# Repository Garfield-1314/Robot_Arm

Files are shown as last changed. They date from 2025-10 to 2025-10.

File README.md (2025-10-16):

# Robot_Arm

## 项目简介
本项目为一个多自由度的机械臂系统，包含机械结构设计、固件开发（基于Arduino）、OpenMV视觉识别、以及多种应用示例（如物块抓取、垃圾分类、三子棋等）。适用于机器人学习、人工智能实验、机械臂控制等场景。

## Project Description
This project is a multi-degree-of-freedom desktop robotic arm system, including mechanical design, firmware development (Arduino-based), OpenMV vision recognition, and various application examples (such as object grasping, garbage classification, tic-tac-toe, etc.). It is suitable for robotics learning, AI experiments, and robotic arm control scenarios.

---

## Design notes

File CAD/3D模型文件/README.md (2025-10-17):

# 机器人手臂 CAD 3D模型文件

## 文件说明

- `ROBOT ARM v30.3mf`：3MF 3D打印机分盘文件，可使用拓竹3D打印机打印：1，2盘为天蓝色；3盘为粉色；4盘为白色；5盘为黄色；6盘蓝色；7盘黑色
- `ROBOT ARM v30.step`：STEP格式的机械臂三维模型文件。

## 使用方法

1. 使用支持3MF或STEP格式的CAD软件（如SolidWorks、Fusion 360、AutoCAD等）打开对应文件。
2. 可用于3D打印、机械设计、仿真等场景。

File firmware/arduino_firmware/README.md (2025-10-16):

# Arduino Robot Arm Firmware / Arduino 机械臂固件

## 简介 | Introduction
本项目为基于 Arduino 平台的机械臂控制固件，适用于 ESP32（如 Wemos D1 R32）等主控板。固件实现了机械臂的基本运动控制、插补算法、末端执行器（如舵机夹爪）控制、限位检测、命令解析等功能。

This project is a robot arm control firmware based on the Arduino platform, suitable for ESP32 (such as Wemos D1 R32) and other mainboards. The firmware implements basic motion control, interpolation algorithms, end-effector (such as servo gripper) control, endstop detection, command parsing, and more.

## 主要功能 | Main Features
- 多轴步进电机控制，支持 Ramps 驱动板
- 运动插补算法，实现平滑轨迹规划
- 舵机夹爪控制
- 端点限位检测，保证运动安全
- 命令解析与队列管理，支持外部串口/网络指令
- 日志记录与调试输出

- Multi-axis stepper motor control, supports Ramps driver board
- Motion interpolation algorithm for smooth trajectory planning
- Servo gripper control
- Endstop detection for safe operation
- Command parsing and queue management, supports external serial/network commands
- Logging and debug output

## 主要文件说明 | Main Files
- `arduino_firmware.ino`：主程序入口 | Main program entry
- `RampsStepper.*`：步进电机控制与驱动 | Stepper motor control and driver
- `interpolation.*`：插补算法实现 | Interpolation algorithm
- `servo_gripper.*`：舵机夹爪控制 | Servo gripper control
- `endstop.*`：限位开关检测 | Endstop detection
- `command.*`：命令解析与执行 | Command parsing and execution
- `equipment.*`：机械臂设备抽象 | Robot arm equipment abstraction
- `logger.*`：日志与调试输出 | Logging and debug output
- `config*.h`：硬件配置（如引脚定义、参数设置）| Hardware configuration (pin definitions, parameters)
- `pinout/`：不同主控板的引脚映射 | Pin mapping for different mainboards

## 使用说明 | Usage
1. 根据实际硬件修改 `config.h` 和 `pinout/` 下的引脚定义。
2. 使用 Arduino IDE 或 PlatformIO 编译并上传固件到主控板。
3. 通过串口或网络发送控制指令，实现机械臂运动。

1. Modify `config.h` and pin definitions in `pinout/` according to your hardware.
2. Compile and upload the firmware to the mainboard using Arduino IDE or PlatformIO.
3. Send control commands via serial or network to operate the robot arm.

## 适用硬件 | Supported Hardware
- 主控板：ESP32 等
- 舵机、限位开关等外设

- Mainboard: ESP32 (e.g. Wemos D1 R32), Arduino Mega, etc.
- Servo, endstop switches, and other peripherals

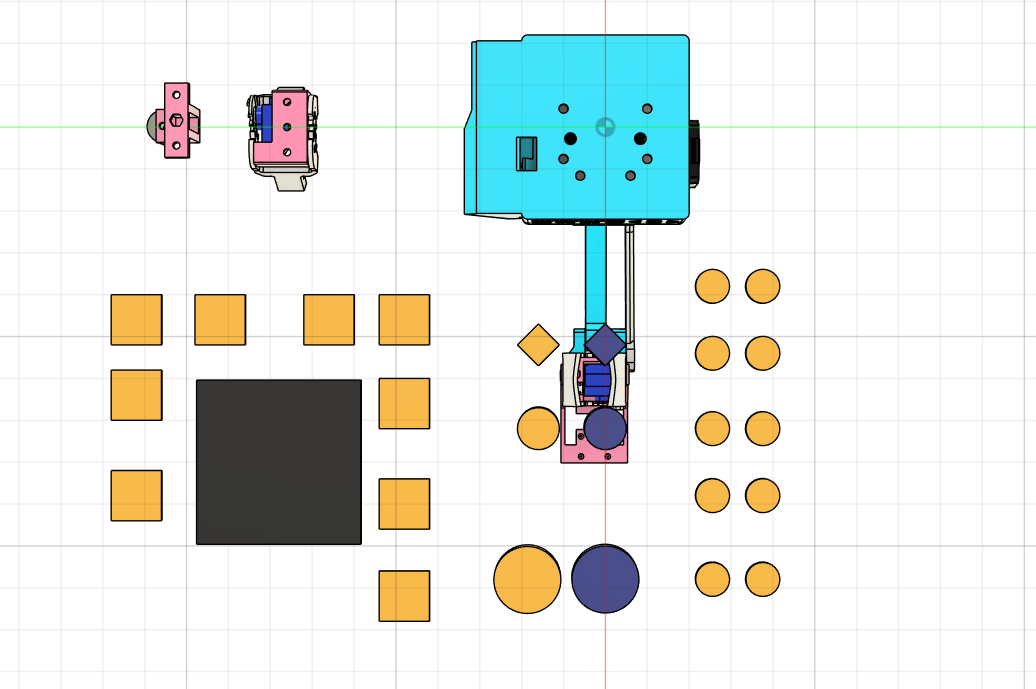
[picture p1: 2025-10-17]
CAD/3D模型文件/底视图.png

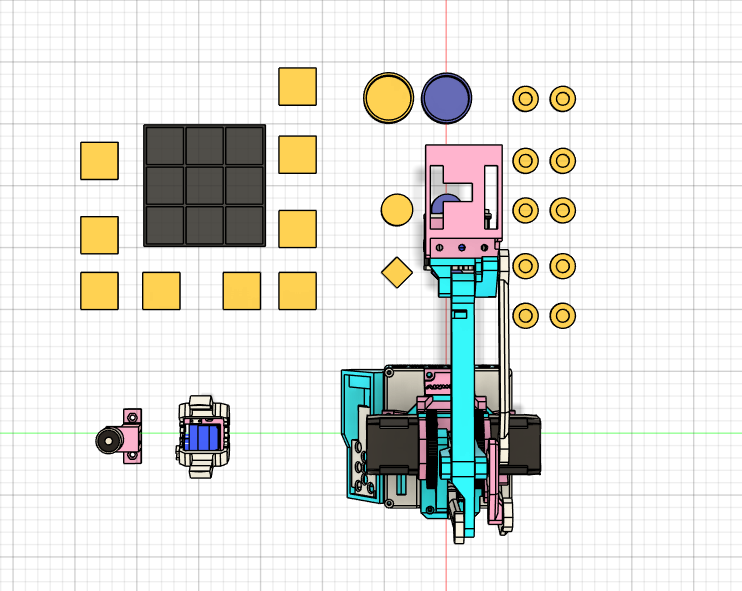
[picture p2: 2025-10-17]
CAD/3D模型文件/顶视图.png

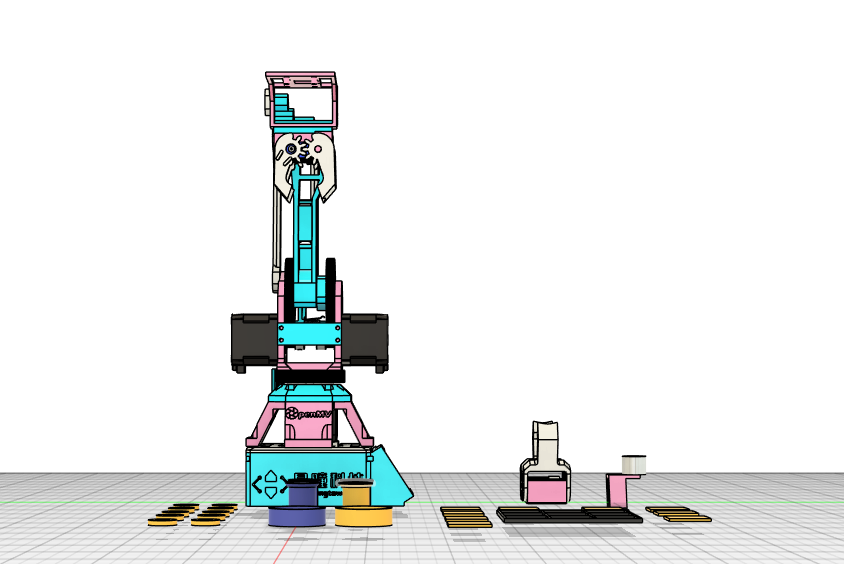
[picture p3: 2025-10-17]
CAD/3D模型文件/右视图.png

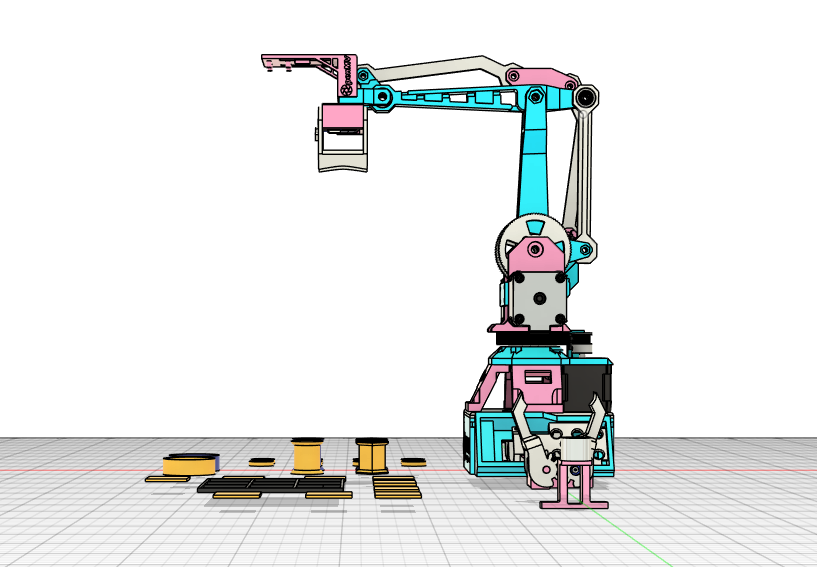
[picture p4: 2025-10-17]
CAD/3D模型文件/后视图.png

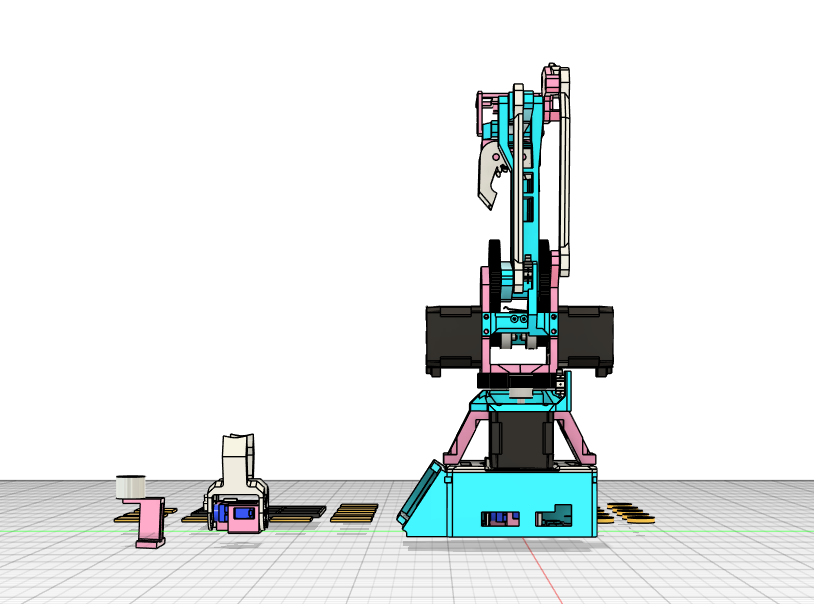
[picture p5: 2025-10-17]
CAD/3D模型文件/左视图.png

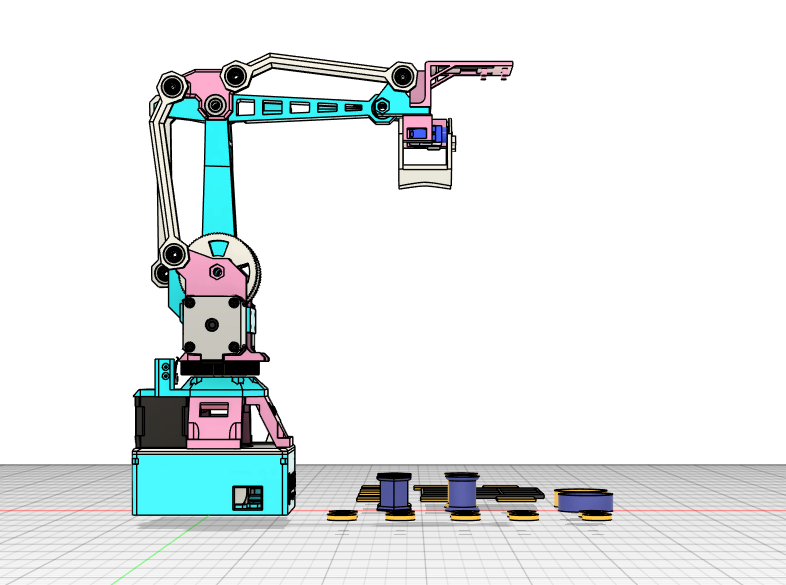
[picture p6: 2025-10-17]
CAD/3D模型文件/前视图.png

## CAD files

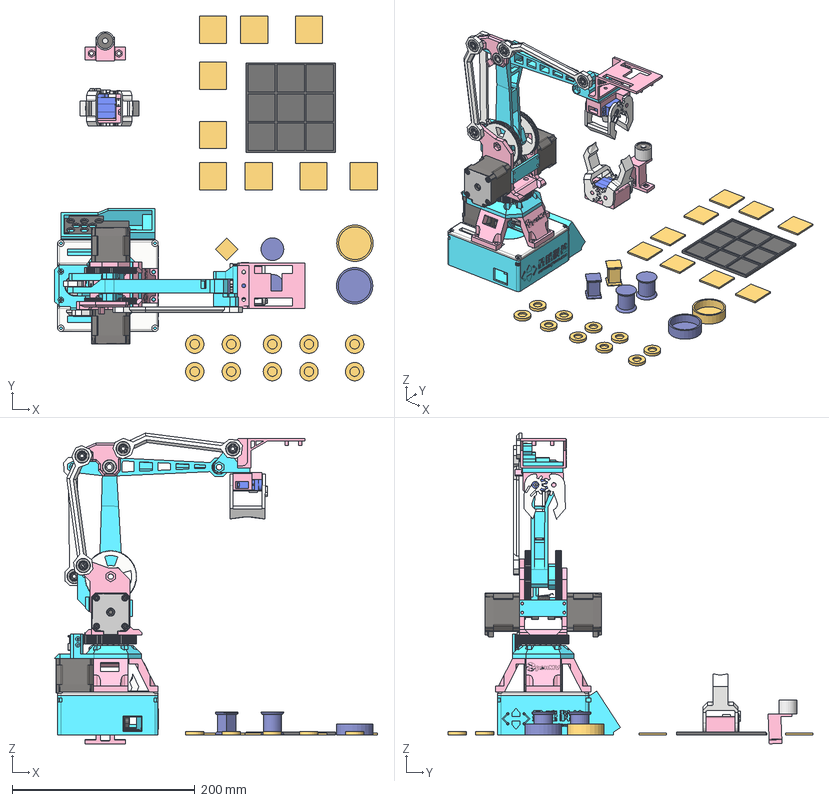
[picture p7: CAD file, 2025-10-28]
CAD/3D模型文件/ROBOT ARM v40.step
353.5 x 399.0 x 340.1 mm
零部件2
零部件2_1
零部件3
零部件4
零部件3_1
零部件4_1
零部件5
零部件3_3 x 3
零部件3_2 x 3
零部件3_4 x 3
零部件2_2
零部件2_3
零部件2_4
零部件3_5 x 7
零部件2_5 x 2
零部件2_6
零部件2_7
零部件2_8
零部件2_9
零部件3_6 x 6
零部件2_10
零部件2_11
零部件2_12
零部件2_13
零部件1
零部件2_14
零部件3_7
零部件4_2
零部件1_1
底座_1
PCB盖
零部件1_2
零部件2_15
零部件2_16
零部件3_8
零部件4_3
零部件2_17
零部件2_18
零部件2_19
零部件2_20
零部件2_21
零部件3_9
零部件4_4
零部件2_22
hand_8
零部件2_23
零部件1_3
零部件1_4
零部件1_5 x 3
零部件2_24
零部件3_10
三子棋棋子 x 10
零部件4_5
零部件5_1
棋盘

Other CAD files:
CAD/3D模型文件/ROBOT ARM v40.3mf
CAD/3D模型文件/ROBOT ARM v40.stl

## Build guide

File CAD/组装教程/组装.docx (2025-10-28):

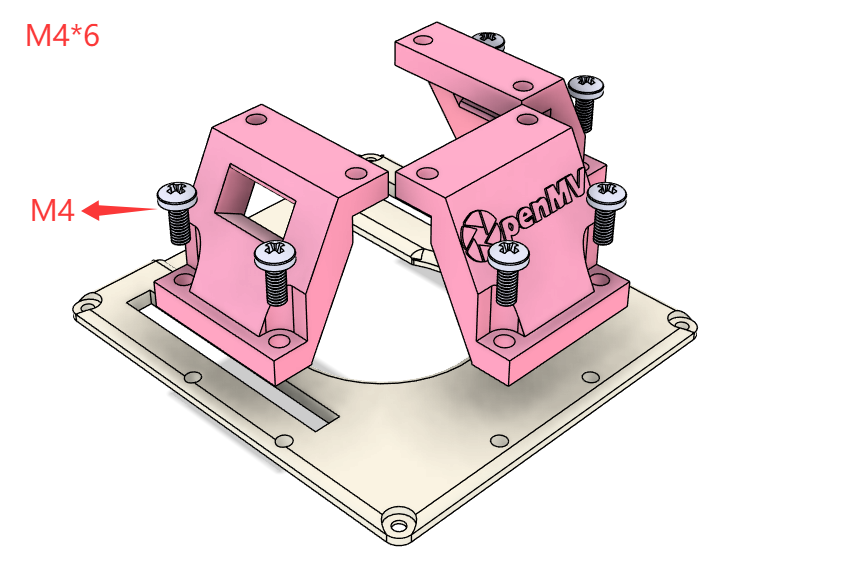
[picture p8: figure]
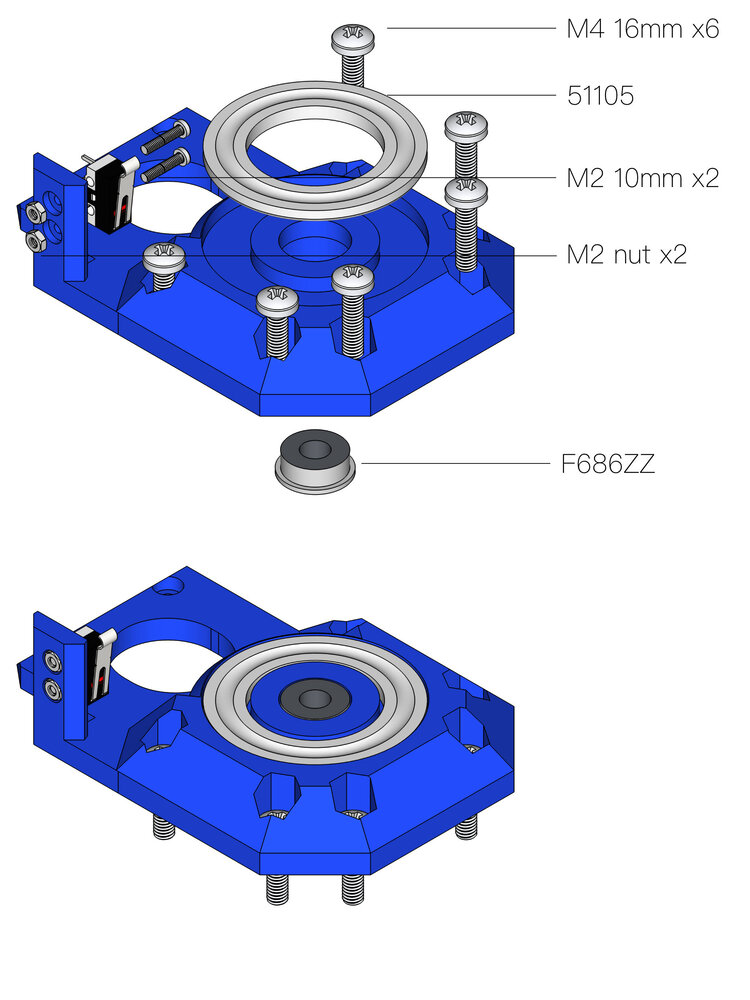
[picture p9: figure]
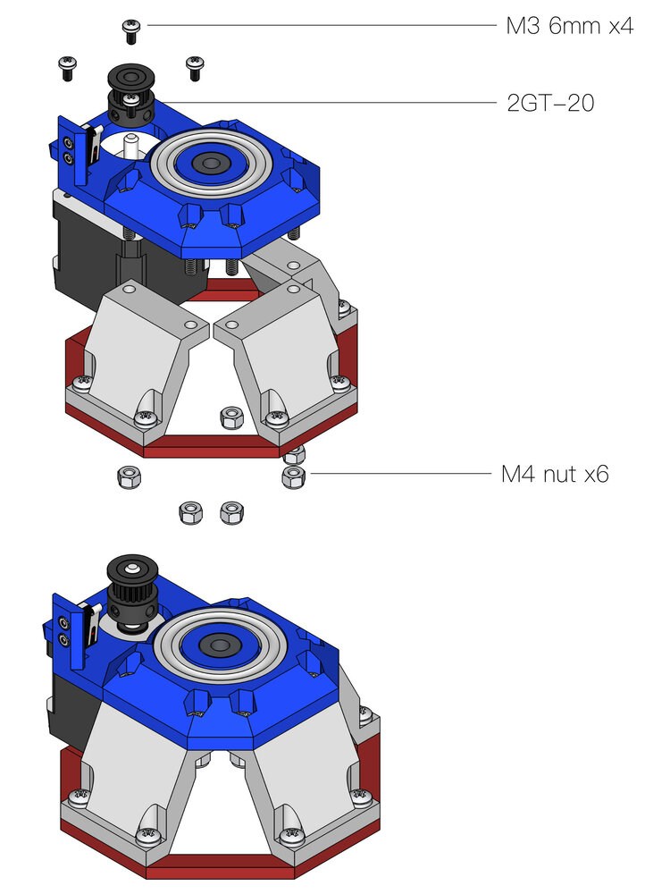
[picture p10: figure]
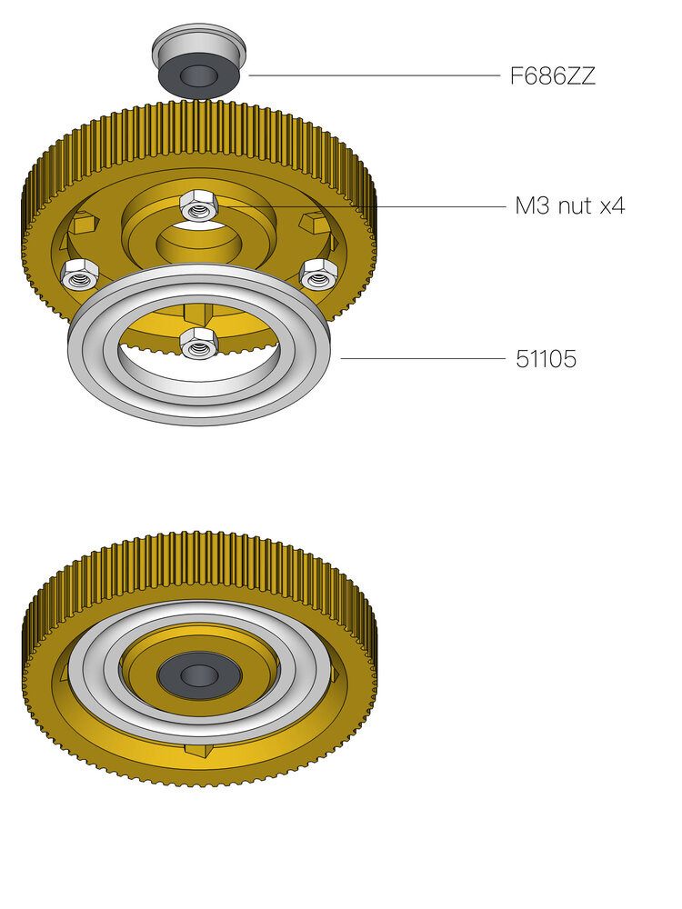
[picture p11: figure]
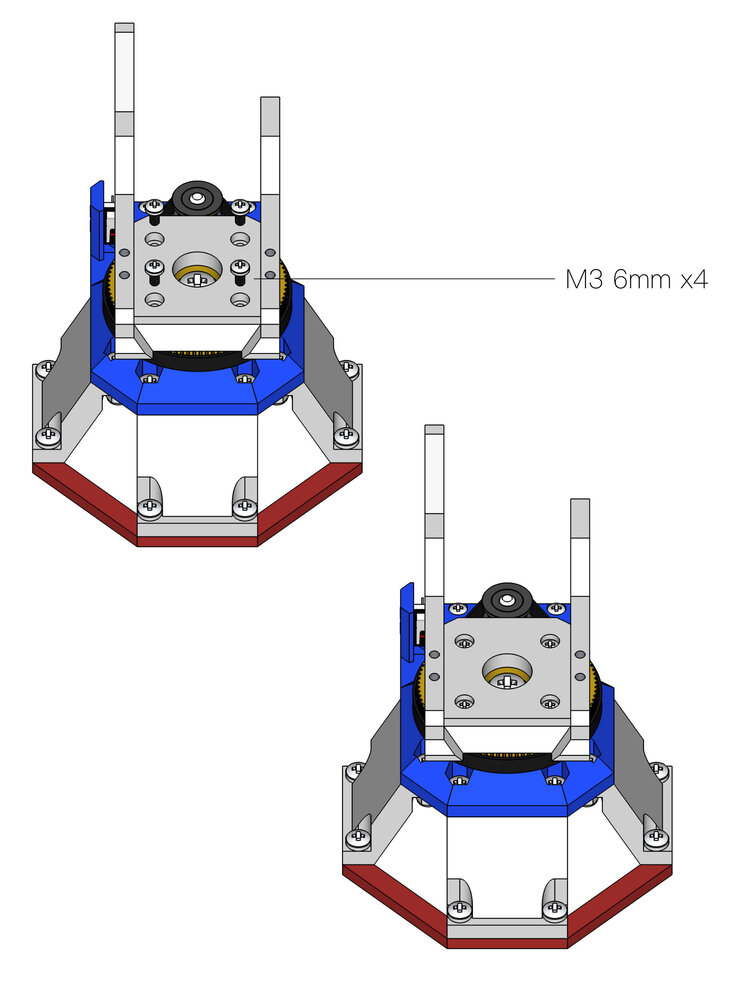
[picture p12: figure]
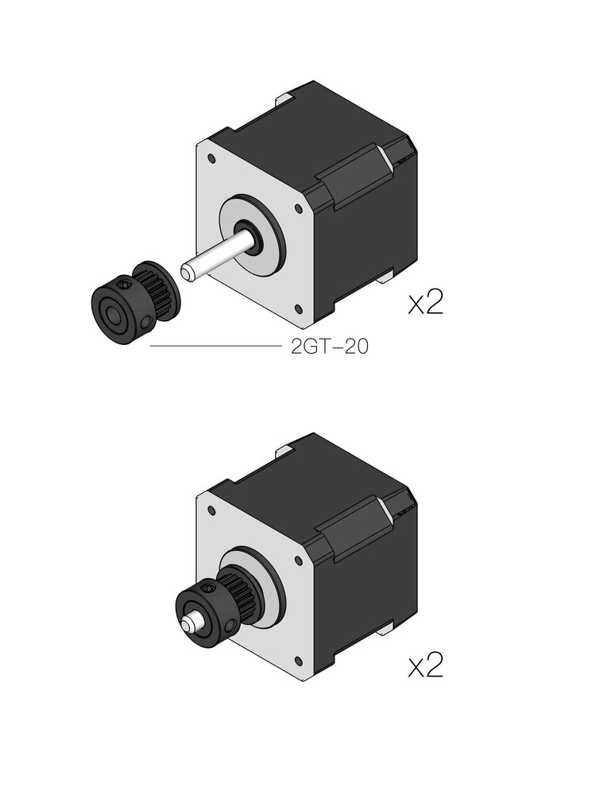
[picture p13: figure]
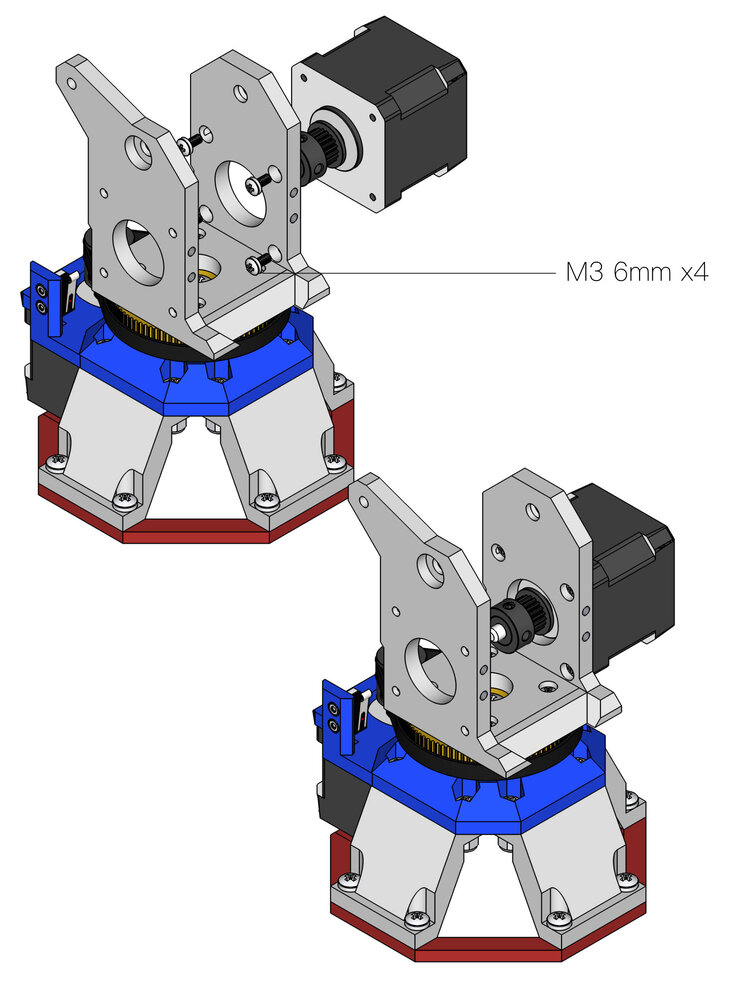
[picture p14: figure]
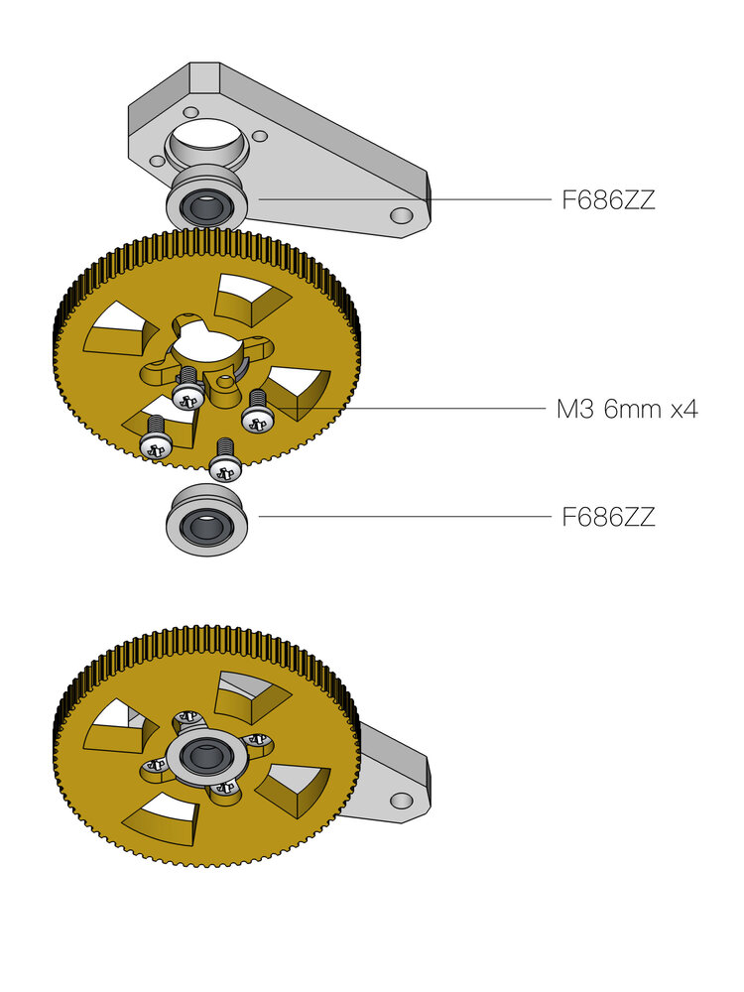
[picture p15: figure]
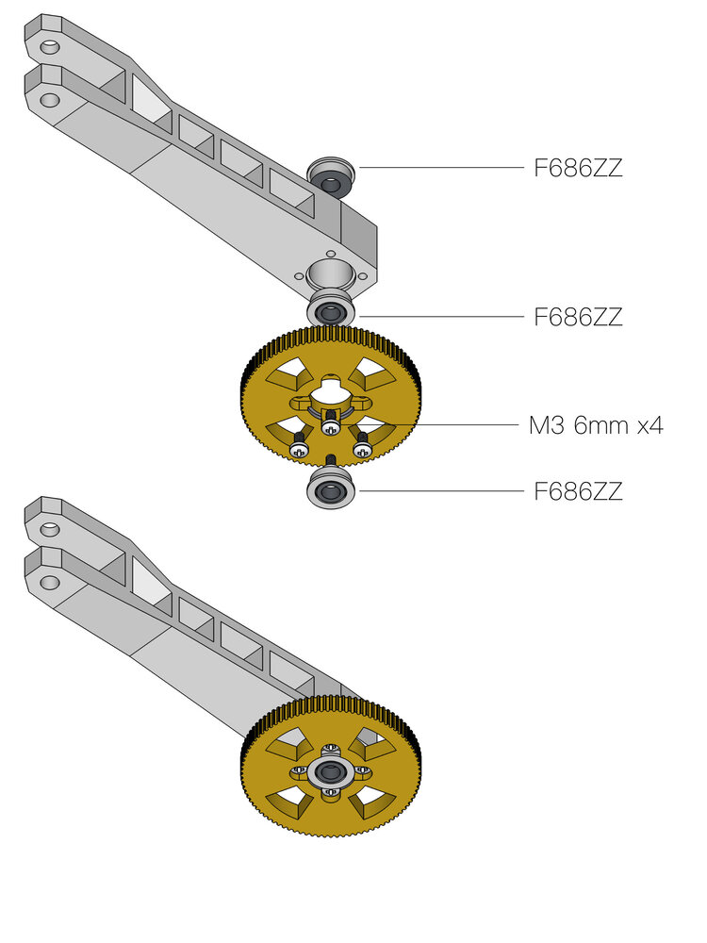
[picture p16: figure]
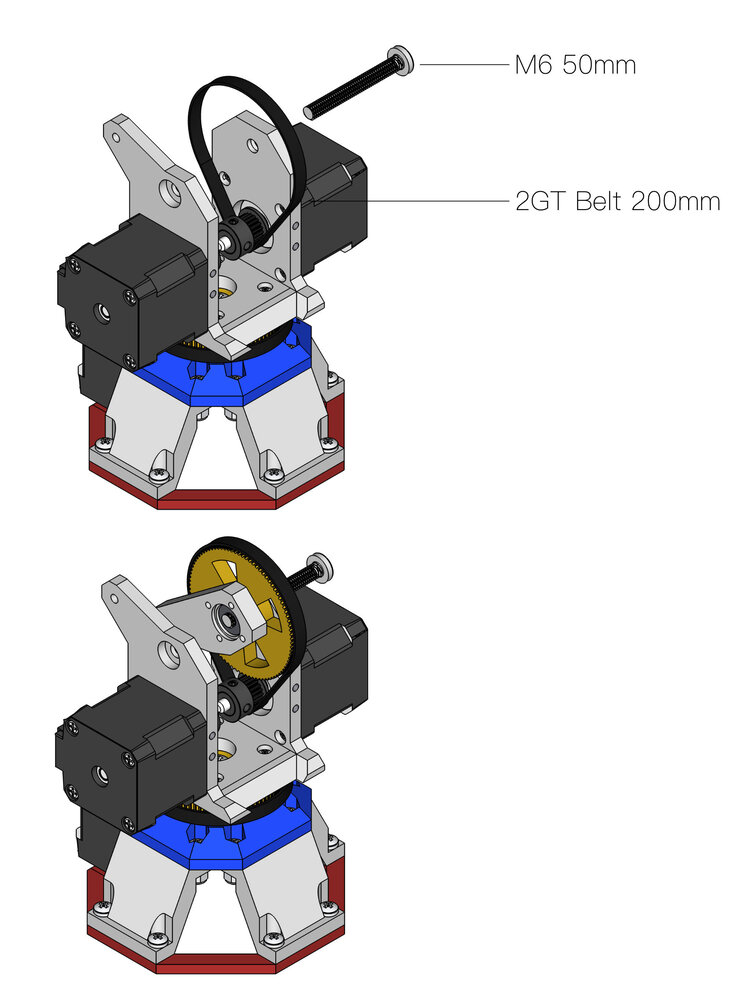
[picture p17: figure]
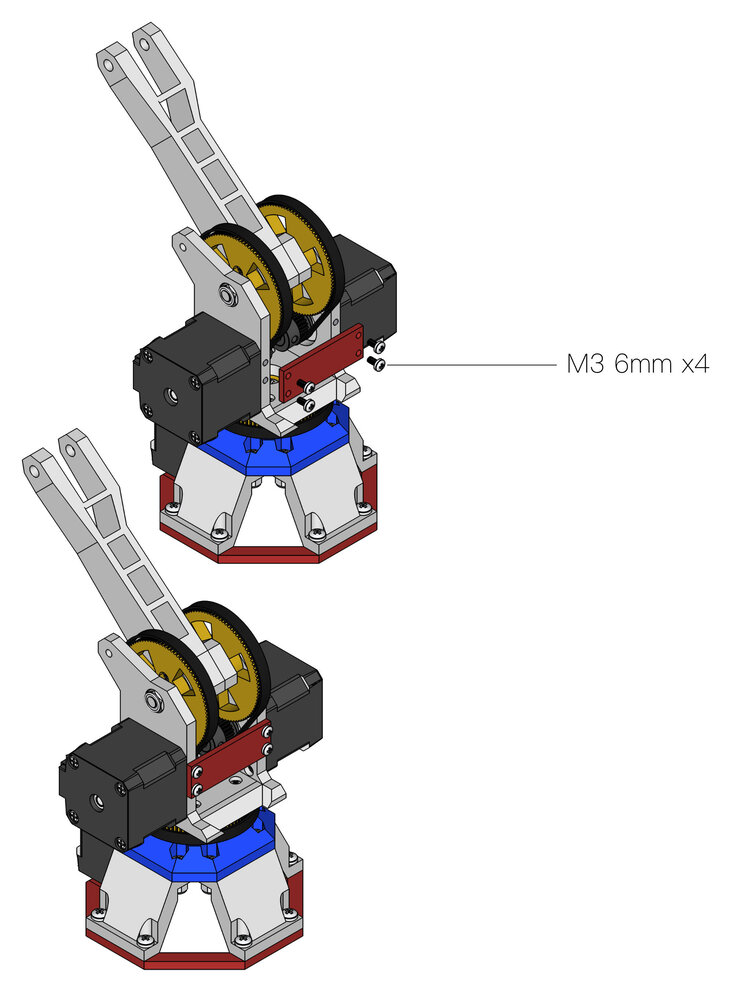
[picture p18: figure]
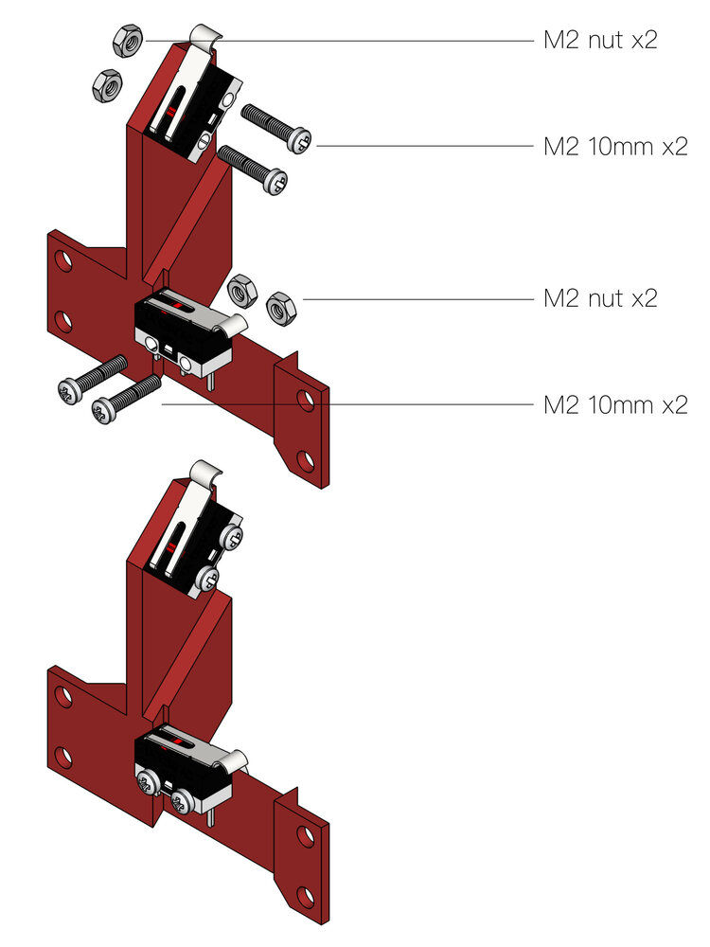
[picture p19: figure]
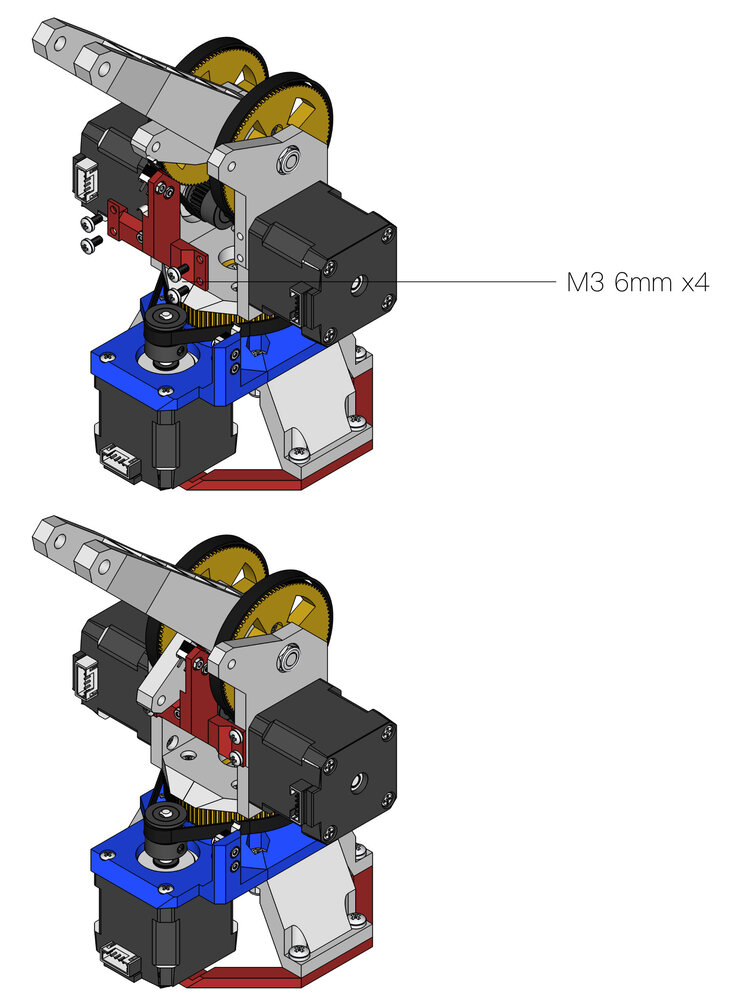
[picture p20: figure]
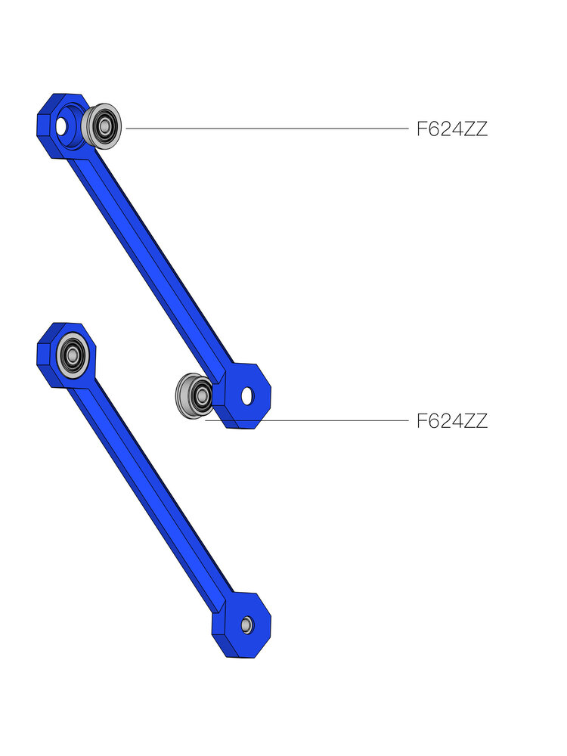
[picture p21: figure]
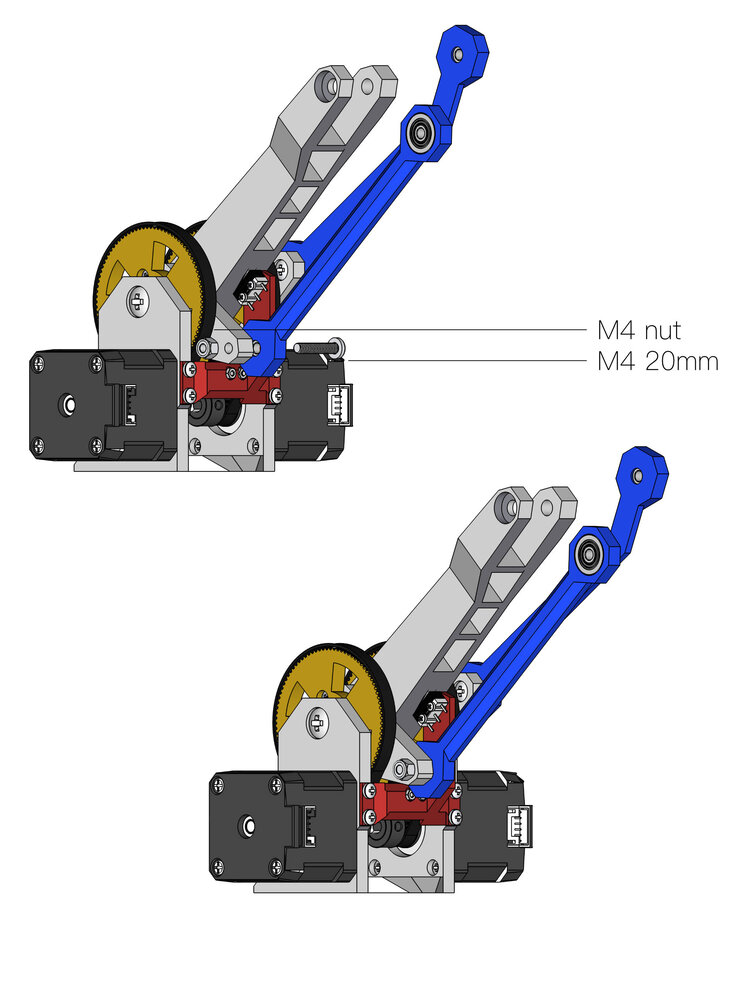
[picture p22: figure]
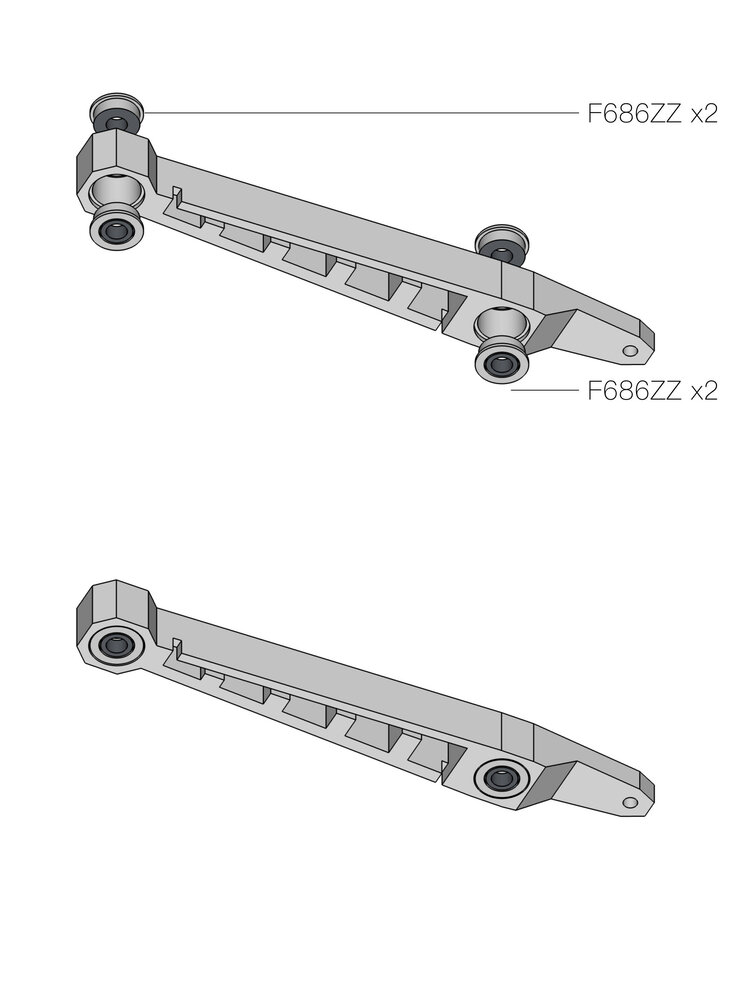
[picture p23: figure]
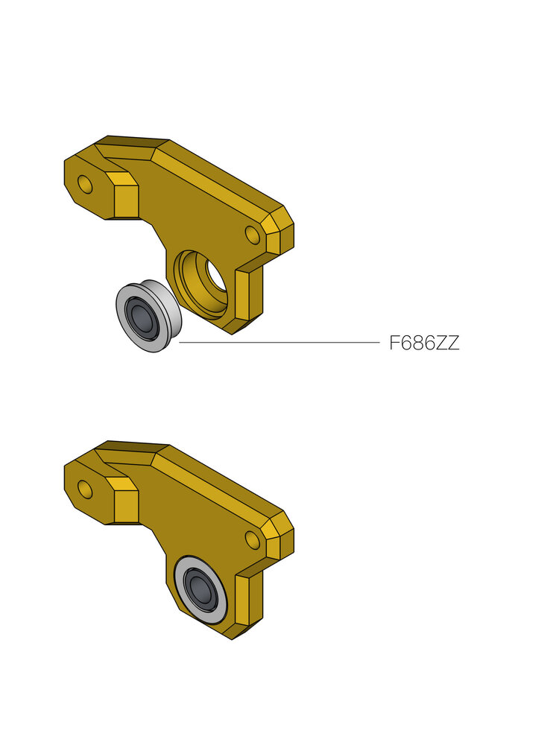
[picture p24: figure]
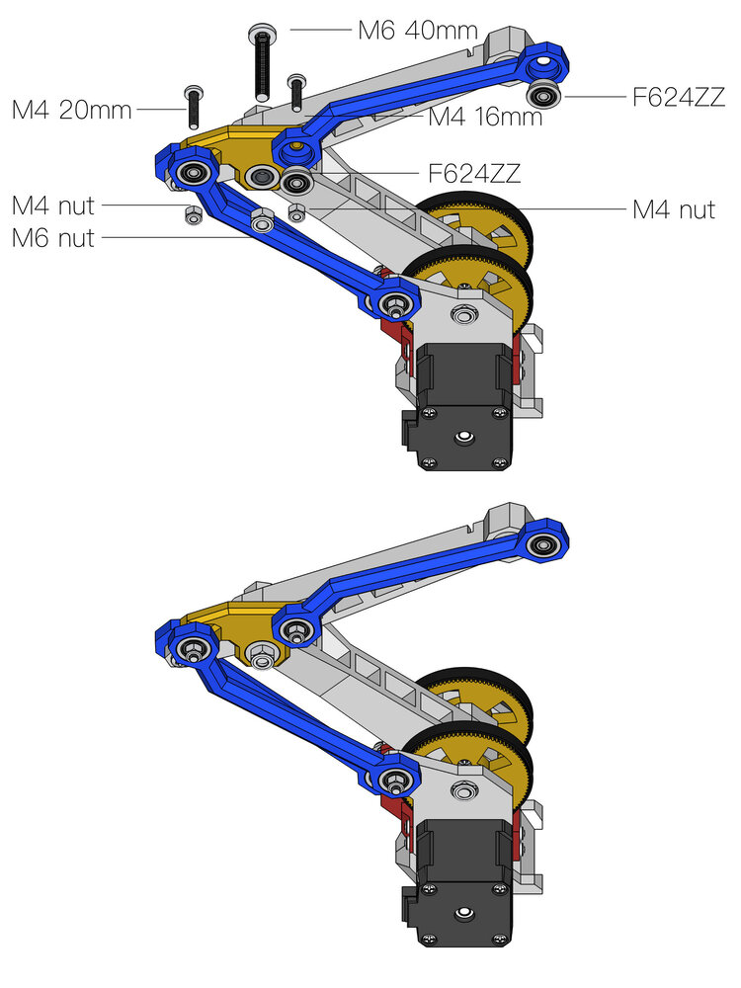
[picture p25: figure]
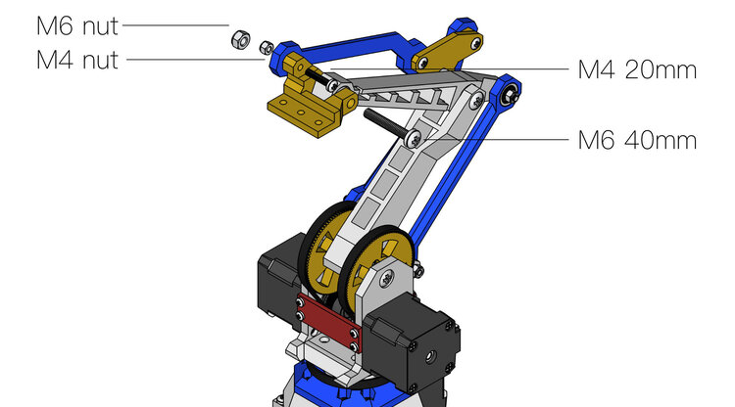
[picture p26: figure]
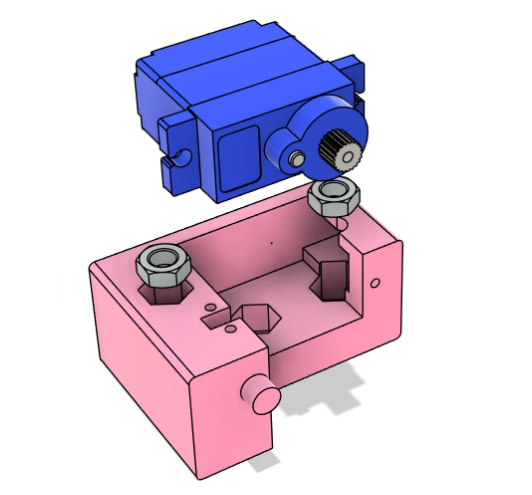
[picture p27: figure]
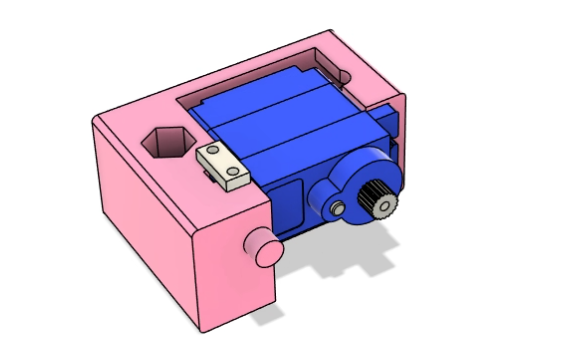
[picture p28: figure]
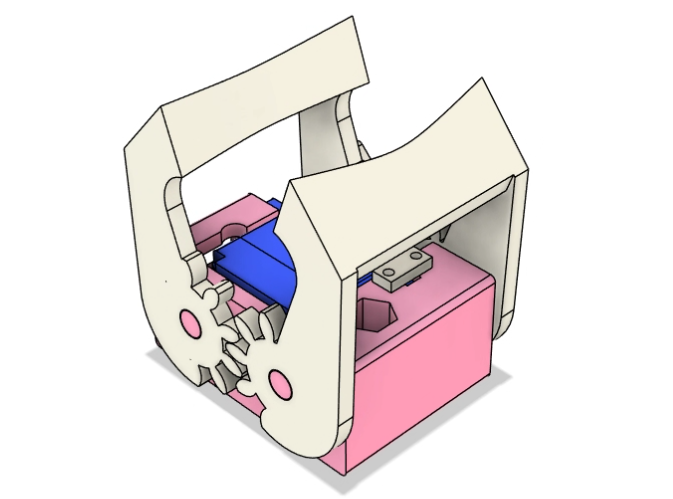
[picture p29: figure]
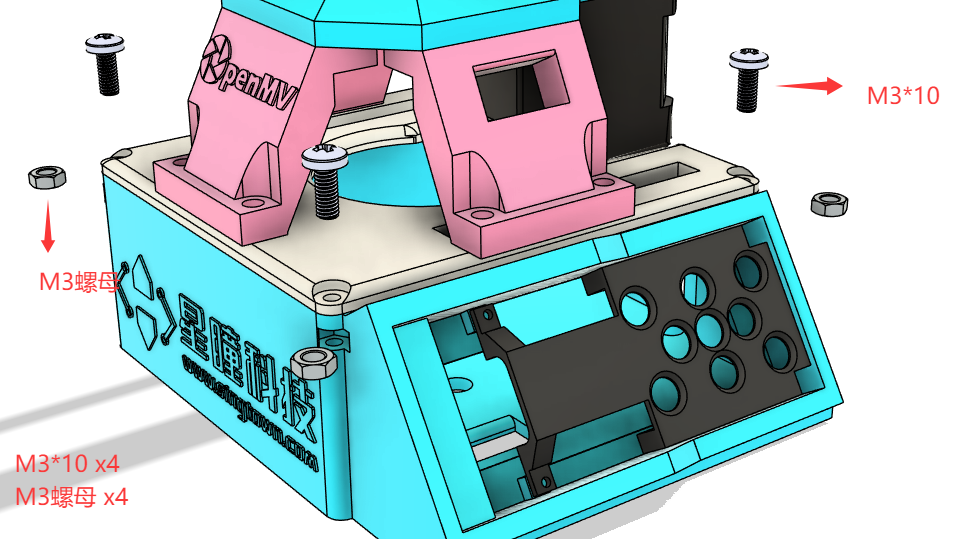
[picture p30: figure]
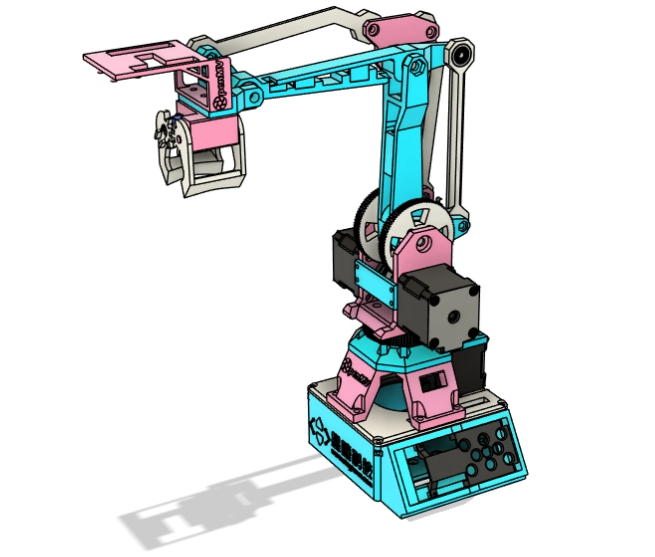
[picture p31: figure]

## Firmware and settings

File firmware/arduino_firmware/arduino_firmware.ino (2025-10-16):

//OPENMV ROBOT ARM V1 
//Base on 20SFFACTORY COMMUNITY ROBOT FIRMWARE VERSION: V0.81
//Using ESP32-S3


#include <Arduino.h>
//GENERAL CONFIG SETTINGS
#include "config.h"

#include "robotGeometry.h"
#include "interpolation.h"
#include "RampsStepper.h"
#include "queue.h"
#include "command.h"
#include "equipment.h"
#include "endstop.h"
#include "logger.h"
//INCLUDE SERVO GRIPPER ONLY
#include "servo_gripper.h"

#include "ad_key.h" // 引入AD按键检测模块

// ONLY INCLUDE ESP32 PINOUT & CONFIG
#include "pinout/pinout_wemosD1R32.h"
#include "config_esp32.h"
#include "NVS.h"
NVS nvs;

//STEPPER OBJECTS (ESP32 ONLY)
RampsStepper stepperHigher(X_STEP_PIN, X_DIR_PIN, X_ENABLE_PIN, INVERSE_X_STEPPER, MAIN_GEAR_TEETH, MOTOR_GEAR_TEETH, MICROSTEPS, STEPS_PER_REV);
RampsStepper stepperLower(Y_STEP_PIN, Y_DIR_PIN, Y_ENABLE_PIN, INVERSE_Y_STEPPER, MAIN_GEAR_TEETH, MOTOR_GEAR_TEETH, MICROSTEPS, STEPS_PER_REV);
RampsStepper stepperRotate(Z_STEP_PIN, Z_DIR_PIN, Z_ENABLE_PIN, INVERSE_Z_STEPPER, MAIN_GEAR_TEETH, MOTOR_GEAR_TEETH, MICROSTEPS, STEPS_PER_REV);


#if RAIL
  RampsStepper stepperRail(E0_STEP_PIN, E0_DIR_PIN, E0_ENABLE_PIN, INVERSE_E0_STEPPER, MAIN_GEAR_TEETH, MOTOR_GEAR_TEETH, MICROSTEPS, STEPS_PER_REV);
  #define SERVO_PIN 36 // REDEFINE SERVO_PIN FOR RAIL // SHARE WITH Z_MIN_PIN
  Endstop* endstopE0 = nullptr;
#endif
//ENDSTOP OBJECTS (ESP32 ONLY)
Endstop* endstopX = nullptr;
Endstop* endstopY = nullptr;
Endstop* endstopZ = nullptr;

// ADKey按键对象示例（使用pinout定义）
ADKey adKey(ADKEY_PIN);
Servo_Gripper servo_gripper(SERVO_PIN, SERVO_GRIP_DEGREE, SERVO_UNGRIP_DEGREE);
Equipment laser(LASER_PIN);
Equipment pump(PUMP_PIN);
Equipment led(LED_PIN);

//EXECUTION & COMMAND OBJECTS
RobotGeometry geometry(END_EFFECTOR_OFFSET, LOW_SHANK_LENGTH, HIGH_SHANK_LENGTH);
Interpolation interpolator;
Queue<Cmd> queue(QUEUE_SIZE);
Command command;

void setup()
{
  Serial.begin(BAUD);
  // 初始化ADKey
  adKey.begin();
  nvs.begin("home_steps"); // 初始化NVS存储

  int x_home_steps = nvs.getInt("home_steps0", 0);
  int y_home_steps = nvs.getInt("home_steps1", 0);
  int z_home_steps = nvs.getInt("home_steps2", 0);
  int e0_home_steps = nvs.getInt("home_steps3", 0);

  endstopX = new Endstop(X_MIN_PIN, X_DIR_PIN, X_STEP_PIN, X_ENABLE_PIN, X_MIN_INPUT, x_home_steps, HOME_DWELL, false);
  endstopY = new Endstop(Y_MIN_PIN, Y_DIR_PIN, Y_STEP_PIN, Y_ENABLE_PIN, Y_MIN_INPUT, y_home_steps, HOME_DWELL, false);

  endstopZ = new Endstop(Z_MIN_PIN, Z_DIR_PIN, Z_STEP_PIN, Z_ENABLE_PIN, Z_MIN_INPUT, z_home_steps, HOME_DWELL, false);
  #if RAIL
    endstopE0 = new Endstop(E0_MIN_PIN, E0_DIR_PIN, E0_STEP_PIN, E0_ENABLE_PIN, E0_MIN_INPUT, e0_home_steps, HOME_DWELL, false);
    stepperRail.setPosition(0);
  #endif

  stepperHigher.setPositionRad(PI / 2.0); // 90°
  stepperLower.setPositionRad(0);         // 0°
  stepperRotate.setPositionRad(0);        // 0°
  if (HOME_ON_BOOT) { //HOME DURING SETUP() IF HOME_ON_BOOT ENABLED
    homeSequence_UNO(); 
    Logger::logINFO("ROBOT ONLINE");
  } else {
    setStepperEnable(false); //ROBOT ADJUSTABLE BY HAND AFTER TURNING ON
    if (HOME_X_STEPPER && HOME_Y_STEPPER && !HOME_Z_STEPPER){
      Logger::logINFO("ROBOT ONLINE");
      Logger::logINFO("ROTATE ROBOT TO FACE FRONT CENTRE & SEND G28 TO CALIBRATE");
    }
    if (HOME_X_STEPPER && HOME_Y_STEPPER && HOME_Z_STEPPER){
      Logger::logINFO("ROBOT ONLINE");
      Logger::logINFO("SEND G28 TO CALIBRATE");
    }
    if (!HOME_X_STEPPER && !HOME_Y_STEPPER){
      Logger::logINFO("ROBOT ONLINE");
      Logger::logINFO("HOME ROBOT MANUALLY & SEND G28 TO CALIBRATE");
    }
  }
  interpolator.setInterpolation(INITIAL_X, INITIAL_Y, INITIAL_Z, INITIAL_E0, INITIAL_X, INITIAL_Y, INITIAL_Z, INITIAL_E0);
}


int flag = 0;

void loop() {
  // 读取ADKey原始值和按键编号
  int adRaw = adKey.readRaw();

  interpolator.updateActualPosition();
  geometry.set(interpolator.getXPosmm(), interpolator.getYPosmm(), interpolator.getZPosmm());
  stepperRotate.stepToPositionRad(-geometry.getRotRad());
  stepperLower.stepToPositionRad(-geometry.getLowRad());
  stepperHigher.stepToPositionRad(-geometry.getHighRad());
  #if RAIL
    stepperRail.stepToPositionMM(-interpolator.getEPosmm(), STEPS_PER_MM_RAIL);
  #endif
  stepperRotate.update();
  stepperLower.update();
  stepperHigher.update();
  #if RAIL
    stepperRail.update();
  #endif

  if (!queue.isFull()) {
    if (command.handleGcode()) {
      queue.push(command.getCmd());
    }
  }
  if ((!queue.isEmpty()) && interpolator.isFinished()) {
    executeCommand(queue.pop());
    if (PRINT_REPLY) {
      Serial.println(PRINT_REPLY_MSG);
    }
  }
  
  if (millis() % 500 < 250) {
    led.cmdOn();
  }
  else {
    led.cmdOff();
  }

}


void executeCommand(Cmd cmd) {
  if (cmd.id == -1) {
    printErr();
    return;
  }
  if ((interpolator.getPosmm().xmm - interpolator.getPosOffset().xmm == cmd.valueX-interpolator.getPosOffset().xmm) && (interpolator.getPosmm().ymm - interpolator.getPosOffset().ymm == cmd.valueY-interpolator.getPosOffset().ymm )&& 
  (interpolator.getPosmm().zmm - interpolator.getPosOffset().zmm == cmd.valueZ-interpolator.getPosOffset().zmm) && (interpolator.getPosmm().emm - interpolator.getPosOffset().emm == cmd.valueE-interpolator.getPosOffset().emm))
  {
    Serial.print(F("MOVE COMPLETE\r\n"));
    flag = 0;
  }

  if (cmd.id == 'G') {
    switch (cmd.num) {
    case 0:
    case 1:
      Point posoffset;
      posoffset = interpolator.getPosOffset();      
      cmdMove(cmd, interpolator.getPosmm(), posoffset, command.isRelativeCoord);
      interpolator.setInterpolation(cmd.valueX, cmd.valueY, cmd.valueZ, cmd.valueE, cmd.valueF);
      Logger::logINFO("LINEAR MOVE: [X:" + String(cmd.valueX-posoffset.xmm) + " Y:" + String(cmd.valueY-posoffset.ymm) + " Z:" + String(cmd.valueZ-posoffset.zmm) + " E:" + String(cmd.valueE-posoffset.emm)+"]");
      flag = 1;
      break;
    case 4: cmdDwell(cmd); break;
    case 28: homeSequence_UNO();break;
    case 90: command.cmdToAbsolute(); break; // ABSOLUTE COORDINATE MODE
    case 91: command.cmdToRelative(); break; // RELATIVE COORDINATE MODE
    case 92: 
      interpolator.resetPosOffset();
      cmdMove(cmd, interpolator.getPosmm(), interpolator.getPosOffset(), false);
      interpolator.setPosOffset(cmd.valueX, cmd.valueY, cmd.valueZ, cmd.valueE);
      break;
    default: printErr();
    }
  }
  else if (cmd.id == 'M') {
    switch (cmd.num) {
    case 1: pump.cmdOn(); break;
    case 2: pump.cmdOff(); break;
    case 3: 
        servo_gripper.cmdOn(); break;
    case 5:
        servo_gripper.cmdOff(); break;
    case 6: laser.cmdOn(); break; 
    case 7: laser.cmdOff(); break;
    case 17: setStepperEnable(true); break;
    case 18: setStepperEnable(false); break;
    case 114: command.cmdGetPosition(interpolator.getPosmm(), interpolator.getPosOffset(), stepperHigher.getPosition(), stepperLower.getPosition(), stepperRotate.getPosition()); break;// Return the current positions of all axis 
    case 119: {
      String endstopMsg = "ENDSTOP: [X:";
  endstopMsg += String(endstopX->state());
      endstopMsg += " Y:";
  endstopMsg += String(endstopY->state());
      endstopMsg += " Z:";
  endstopMsg += String(endstopZ->state());
      #if RAIL
        endstopMsg += " E:";
        endstopMsg += String(endstopE0.state());
      #endif
      endstopMsg += "]";
      Logger::logINFO(endstopMsg);
      break;}
    case 205:
      interpolator.setSpeedProfile(cmd.valueS); 
      Logger::logINFO("SPEED PROFILE: [" + String(interpolator.speed_profile) + "]");
      break;
    case 280:
      servo_gripper.set_degree(cmd.valueP);
      Logger::logINFO("SERVO: [" + String(cmd.valueP) + "]");
      break;
    case 281:
      Logger::logINFO("HOMING STEPS: x[" + String(cmd.valueX) + "], y[" + String(cmd.valueY) + "], z[" + String(cmd.valueZ) + "]");
      nvs.putInt("home_steps0", cmd.valueX);
      nvs.putInt("home_steps1", cmd.valueY);
      nvs.putInt("home_steps2", cmd.valueZ);
      #if RAIL
        nvs.putInt("home_steps3", cmd.valueE);
      #endif
      ESP.restart();
      break;
    default: printErr();
    }
  }
  else {
    printErr();
  }
}

void setStepperEnable(bool enable){
  stepperRotate.enable(enable);
  stepperLower.enable(enable);
  stepperHigher.enable(enable);
  #if RAIL
    stepperRail.enable(enable);
  #endif
}


//DUE TO UNO CNC SHIELD LIMIT, 1 EN PIN SERVES 3 MOTORS, HENCE DIFFERENT HOMESEQUENCE IS REQUIRED
void homeSequence_UNO(){
  #if RAIL
    endstopE0(E0_MIN_PIN, E0_DIR_PIN, E0_STEP_PIN, E0_ENABLE_PIN, E0_MIN_INPUT, nvs.getInt("home_steps3",0), HOME_DWELL, false);
  #endif
  
  #if GRIPPER == SERVO
  if (servo_gripper.readDegree() != SERVO_UNGRIP_DEGREE){
    servo_gripper.cmdOff();
  }
  #endif
  if (HOME_Y_STEPPER && HOME_X_STEPPER){
    while (!endstopY->state() || !endstopX->state()){
      endstopX->oneStepToEndstop(!INVERSE_X_STEPPER);
      endstopY->oneStepToEndstop(!INVERSE_Y_STEPPER);
    }
    endstopX->homeOffset(!INVERSE_X_STEPPER);
    endstopY->homeOffset(!INVERSE_Y_STEPPER);
  } else {
  setStepperEnable(true);
  endstopX->homeOffset(!INVERSE_X_STEPPER);
  endstopY->homeOffset(!INVERSE_Y_STEPPER);
  }
  if (HOME_Z_STEPPER){
    endstopZ->home(INVERSE_Z_STEPPER); //INDICATE STEPPER HOMING DIRECDTION
  }
  #if RAIL
    if (HOME_E0_STEPPER){
      endstopE0.home(!INVERSE_E0_STEPPER);
    }
  #endif
  interpolator.setInterpolation(INITIAL_X, INITIAL_Y, INITIAL_Z, INITIAL_E0, INITIAL_X, INITIAL_Y, INITIAL_Z, INITIAL_E0);
  Logger::logINFO("HOMING COMPLETE");
}

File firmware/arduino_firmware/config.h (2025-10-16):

#ifndef CONFIG_H_
#define CONFIG_H_

//SERIAL SETTINGS
#define BAUD 115200

//CHOICE OF MCU BOARDS TO DRIVE ROBOT. BY DEFAULT: 0 (MEGA2560)
#define BOARD_CHOICE WEMOSD1R32
     //CHOICES: 
     //  MEGA2560
     //  UNO
     //  WEMOSD1R32
     
     //..DO NOT CHANGE BELOW BOARD VALUES..//
     #define MEGA2560    0 //ARDUINO MEGA2560 & RAMPS 1.4
     #define UNO         1 //ARDUINO UNO & CNC SHIELD
     #define WEMOSD1R32  2 //ESP32 - WEMOS D1 R32 & CNC SHIELD
     //PLEASE SEE & ADJUST ESP32 PARAMETERS IN [config_esp32.h]

//ROBOT ARM LENGTH
//#define SHANK_LENGTH 140.0
#define LOW_SHANK_LENGTH 120.0
#define HIGH_SHANK_LENGTH 120.0

#define END_EFFECTOR_OFFSET 54.0 // LENGTH FROM UPPER SHANK BEARING TO MIDPOINT OF END EFFECTOR IN MM

//INITIAL INTERPOLATION SETTINGS
//  INITIAL_XYZ FORMS VERTICAL LOWER ARM & HORIZONTAL UPPER ARM IN 90 DEGREES
#define INITIAL_X 0.0 // CARTESIAN COORDINATE X  
#define INITIAL_Y (HIGH_SHANK_LENGTH+END_EFFECTOR_OFFSET) // CARTESIAN COORDINATE Y
#define INITIAL_Z LOW_SHANK_LENGTH // CARTESIAN COORDINATE Z

#define INITIAL_E0 0.0 // RAIL STEPPER ENDSTOP POSITION 

//  CALIBRATE HOME STEPS TO REACH DESIRED INITIAL_XYZ POSITIONS
#define X_HOME_STEPS 900  // STEPS FROM X_ENDSTOP TO INITIAL_XYZ FOR UPPER ARM
#define Y_HOME_STEPS 1800 // STEPS FROM Y_ENDSTOP TO INITIAL_XYZ FOR LOWER ARM
#define Z_HOME_STEPS 3780 // STEPS FROM Z_ENDSTOP TO INITIAL_XYZ FOR ROTATION CENTER
#define E0_HOME_STEPS 500 // STEPS FROM E0_ENDSTOP TO INITIAL_E0

//HOMING SETTINGS:
#define HOME_X_STEPPER true // "true" IF ENDSTOP IS INSTALLED
#define HOME_Y_STEPPER true // "true" IF ENDSTOP IS INSTALLED
#define HOME_Z_STEPPER true // "true" IF ENDSTOP IS INSTALLED
#define HOME_E0_STEPPER true // "true" IF ENDSTOP IS INSTALLED
#define HOME_ON_BOOT false // "true" IF HOMING REQUIRED AFTER POWER ON
#define HOME_DWELL 800 // INCREASE TO SLOW DOWN HOMING SPEED

//STEPPER SETTINGS:
#define MICROSTEPS 16 // MICROSTEPPING CONFIGURATION ON RAMPS1.4
#define STEPS_PER_REV 200 // NEMA17 STEPS PER REVOLUTIONw
#define INVERSE_X_STEPPER false // CHANGE IF STEPPER MOVES OTHER WAY
#define INVERSE_Y_STEPPER true // CHANGE IF STEPPER MOVES OTHER WAY
#define INVERSE_Z_STEPPER false // CHANGE IF STEPPER MOVES OTHER WAY
#define INVERSE_E0_STEPPER false // CHANGE IF STEPPER MOVES OTHER WAY

//RAIL SETTINGS:
#define RAIL false // E0 STEPPER USED AS RAIL. SET TO 'false' IF ROBOT ARM IS STATIONARY.
#define STEPS_PER_MM_RAIL 160  // STEPS PER MM FOR RAIL MOTOR
        //FORMULA: STEPS_PER_REV * MICROSTEPS / MOTOR_GEAR_TEETH / 2
#define RAIL_LENGTH 700.0 // MAX LENGTH OF RAIL IN MM

//ENDSTOP SETTINGS:
#define X_MIN_INPUT 0 // OUTPUT VALUE WHEN SWITCH ACTIVATED - NO: 0, NC: 1
#define Y_MIN_INPUT 0 // OUTPUT VALUE WHEN SWITCH ACTIVATED - NO: 0, NC: 1
#define Z_MIN_INPUT 0 // OUTPUT VALUE WHEN SWITCH ACTIVATED - NO: 0, NC: 1
#define E0_MIN_INPUT 0 // OUTPUT VALUE WHEN SWITCH ACTIVATED - NO: 0, NC: 1

//GEAR RATIO SETTINGS
#define MOTOR_GEAR_TEETH 20.0 // 20.0 FOR 20SFFACTORY BELT VERSION   9.0 FOR FTOBLER GEAR VERSION
#define MAIN_GEAR_TEETH 90.0 // 90.0 FOR 20SFFACTORY BELT VERSION   32.0 FOR FTOBLER GEAR VERSION

//EQUIPMENT SETTINGS
#define LASER false // 12V LASER CONNECTED TO LASER_PIN
#define PUMP false // 12V AIR PUMP CONNECTED TO PUMP_PIN
#define FAN_DELAY 120 // FAN ON IN SECONDS

//GRIPPER SETTINGS
// 只保留SERVO相关定义
#define GRIPPER 1 // 1: 9G SERVO OR MG996 SERVO EQUIVALENT
#define SERVO 1
//SERVO GRIPPER SETTINGS
#define SERVO_GRIP_DEGREE 90.0
#define SERVO_UNGRIP_DEGREE 0.0

//COMMAND QUEUE SETTINGS
#define QUEUE_SIZE 15

//PRINT REPLY SETTING
#define PRINT_REPLY false // "true" TO PRINT MSG AFTER ONE COMMAND IS PROCESSED
#define PRINT_REPLY_MSG "ok" // MSG SENT FOR USER'S POST PROCESSING WITH OTHER SOFTWARE

//DEFAULT SPEED PROFILE SETTING 
#define SPEED_PROFILE 2 // OPTIONS BELOW
//0: FLAT SPEED CURVE (CONSTANT SPEED PER MOVEMENT, SUITABLE FOR REALTIME CONTROL SOFTWARE)
//1: ARCTAN APPROX (SLIGHT BELL CURVE ACCELERATION & DECELERATION)
//2: COSIN APPROX (TOTAL BELL CURVE ACCEL FROM 0 & DECEL TO 0, SUITABLE FOR PRESET COMMAND MOVEMENTS)

//LOG SETTINGS
#define LOG_LEVEL 2
//0: ERROR
//1: INFO
//2: DEBUG

//MOVE LIMIT PARAMETERS
#define Z_MIN -140.0 //MINIMUM Z HEIGHT OF TOOLHEAD TOUCHING GROUND
#define Z_MAX (LOW_SHANK_LENGTH+30.0) //SHANK_LENGTH ADDING ARBITUARY NUMBER FOR Z_MAX
#define SHANKS_MIN_ANGLE_COS 0.791436948 
#define SHANKS_MAX_ANGLE_COS -0.774944489 
#define R_MIN (sqrt((sq(LOW_SHANK_LENGTH) + sq(HIGH_SHANK_LENGTH)) - (2*LOW_SHANK_LENGTH*HIGH_SHANK_LENGTH*SHANKS_MIN_ANGLE_COS) ))
#define R_MAX (sqrt((sq(LOW_SHANK_LENGTH) + sq(HIGH_SHANK_LENGTH)) - (2*LOW_SHANK_LENGTH*HIGH_SHANK_LENGTH*SHANKS_MAX_ANGLE_COS) ))

#endif

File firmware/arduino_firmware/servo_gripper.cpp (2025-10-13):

#include "servo_gripper.h"
#include "config.h"

#include <Arduino.h>

#if BOARD_CHOICE == WEMOSD1R32
  #include <ESP32Servo.h>
#else 
  #include <Servo.h>
#endif

Servo_Gripper::Servo_Gripper(int pin, float grip_degree, float ungrip_degree){
  servo_pin = pin;
  servo_grip_deg = grip_degree;
  servo_ungrip_deg = ungrip_degree;
  Servo servo_motor;
}

// 新增舵机驱动代码，IO为36
#if BOARD_CHOICE == WEMOSD1R32
#include <ESP32Servo.h>
#else
#include <Servo.h>
#endif


void Servo_Gripper::set_degree(float deg){
  servo_motor.attach(servo_pin);
  delayMicroseconds(10);
  servo_motor.write(deg);
  delay(300);
  //servo_motor.detach();
}

void Servo_Gripper::cmdOff(){
  servo_motor.attach(servo_pin);
  delayMicroseconds(10);
  servo_motor.write(servo_grip_deg-15);
  delay(300);
  //servo_motor.detach();
}

void Servo_Gripper::cmdOn(){
  servo_motor.attach(servo_pin);
  servo_motor.write(servo_ungrip_deg+10);
  delay(300);
  servo_motor.detach();
  delayMicroseconds(50);
}

float Servo_Gripper::readDegree(){
  float servo_current_degree = servo_motor.read();
  return servo_current_degree;
}

bool Servo_Gripper::isOn(){
  float servo_current_degree = servo_motor.read();
  if (servo_current_degree == servo_grip_deg){
    return true;
  } else {
    return false;
  }
}

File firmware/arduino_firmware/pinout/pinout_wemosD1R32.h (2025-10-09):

#ifndef PINOUT_ESP32WEMOS_H_
#define PINOUT_ESP32WEMOS_H_

#define X_STEP_PIN         8
#define X_DIR_PIN          4 //SHARE WITH E0_MIN_PIN
#define X_ENABLE_PIN       -1
#define X_MIN_PIN          14
#define X_MAX_PIN          -1
 
#define Y_STEP_PIN         7
#define Y_DIR_PIN          3
#define Y_ENABLE_PIN       -1
#define Y_MIN_PIN          16
#define Y_MAX_PIN          -1

#define Z_STEP_PIN         6
#define Z_DIR_PIN          2
#define Z_ENABLE_PIN       -1
#define Z_MIN_PIN          13 //SHARE WITH SERVO_PIN
#define Z_MAX_PIN          -1

#define E0_STEP_PIN        9
#define E0_DIR_PIN         5
#define E0_ENABLE_PIN      -1
#define E0_MIN_PIN         15 //SHARE WITH X_DIR_PIN

#define E1_STEP_PIN        -1
#define E1_DIR_PIN         -1
#define E1_ENABLE_PIN      -1


#define SERVO_PIN          36 //SERVO_PIN FOR STATIONARY

#define PUMP_PIN           45
#define LASER_PIN          -1
#define LED_PIN            1


#define ADKEY_PIN          10  // ADKey 检测IO口定义

#define SDPOWER            -1
#define SDSS               -1

#define FAN_PIN            -1

#define PS_ON_PIN          -1
#define KILL_PIN           -1

#define TEMP_0_PIN         -1
#define TEMP_1_PIN         -1



#endif

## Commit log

2025-10-09 add ad key
    [20GT齿轮.step, 3盘3色（已分好盘）.3mf, 42-38步进电机.step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]
2025-10-10 fix servo
2025-10-11 add-long-key && fix demos && add 24E
    [Robot_arm.py, main.py]
2025-10-11 de data
2025-10-13 git fix ad-key & delete fan
    [Robot_arm.py, arduino_firmware.ino, main.py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]
2025-10-28 更新CAD模型文件，删除部分无用示例代码
    [ROBOT ARM v32.3mf, ROBOT ARM v32.step, ROBOT ARM v32.stl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]
